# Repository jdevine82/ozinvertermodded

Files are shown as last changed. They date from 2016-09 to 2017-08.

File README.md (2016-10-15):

# ozinvertermodded
This git is an opensource project. The orginal design comes from a bloke on Finders Island going by the handle of OZTULES.
He has given the design to the public domain. I have simply penned the schematic down by reverse engineering his PCB as this was not 
written down anywhere. The files here contain the basic version and also a version coming with switchmode regulators. Free for anyone to use.
4/09/16 reworked with switchmode ps for 48-12v conversion. Changed pcb to 10x10. Use this type of regulator http://www.ebay.com.au/itm/DC-DC-Converter-4-5-60V-Adjustable-Step-Down-Buck-LM2596HV-Power-Supply-Module-/261942503087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

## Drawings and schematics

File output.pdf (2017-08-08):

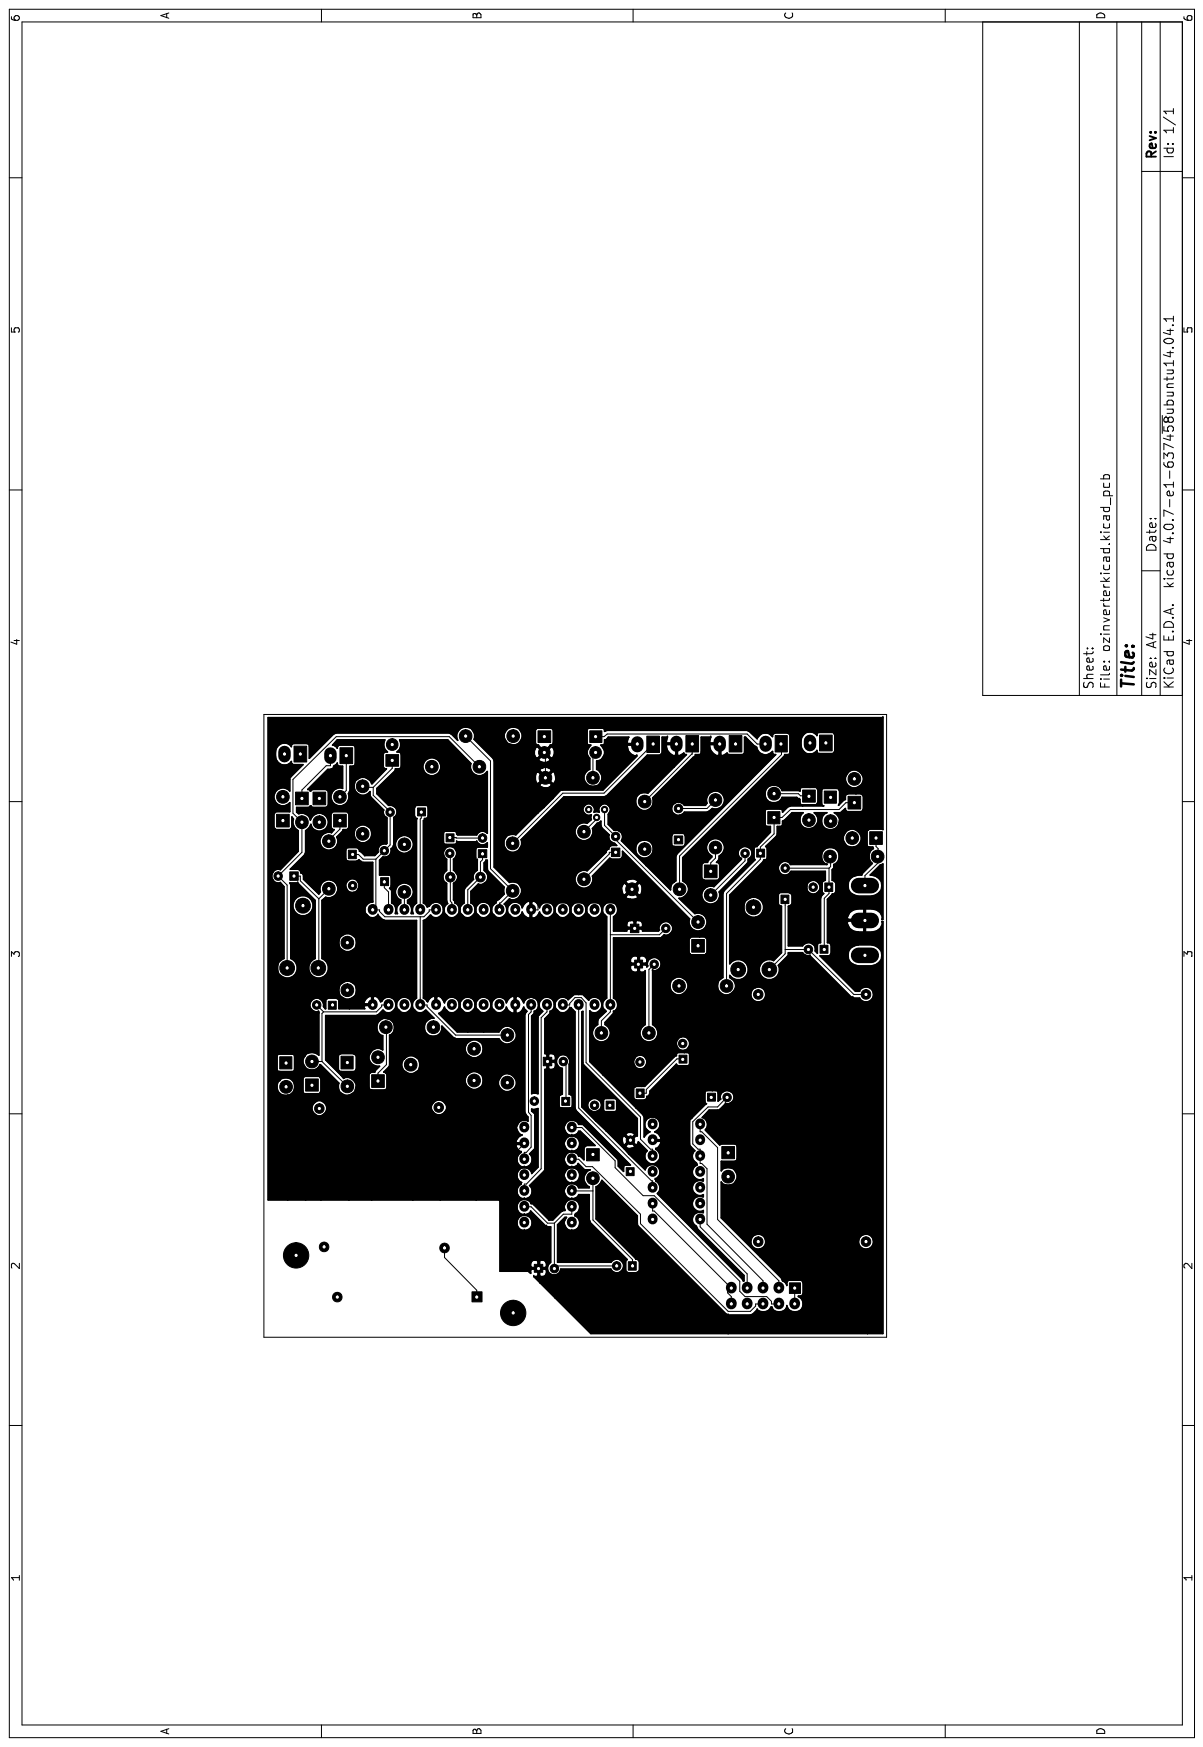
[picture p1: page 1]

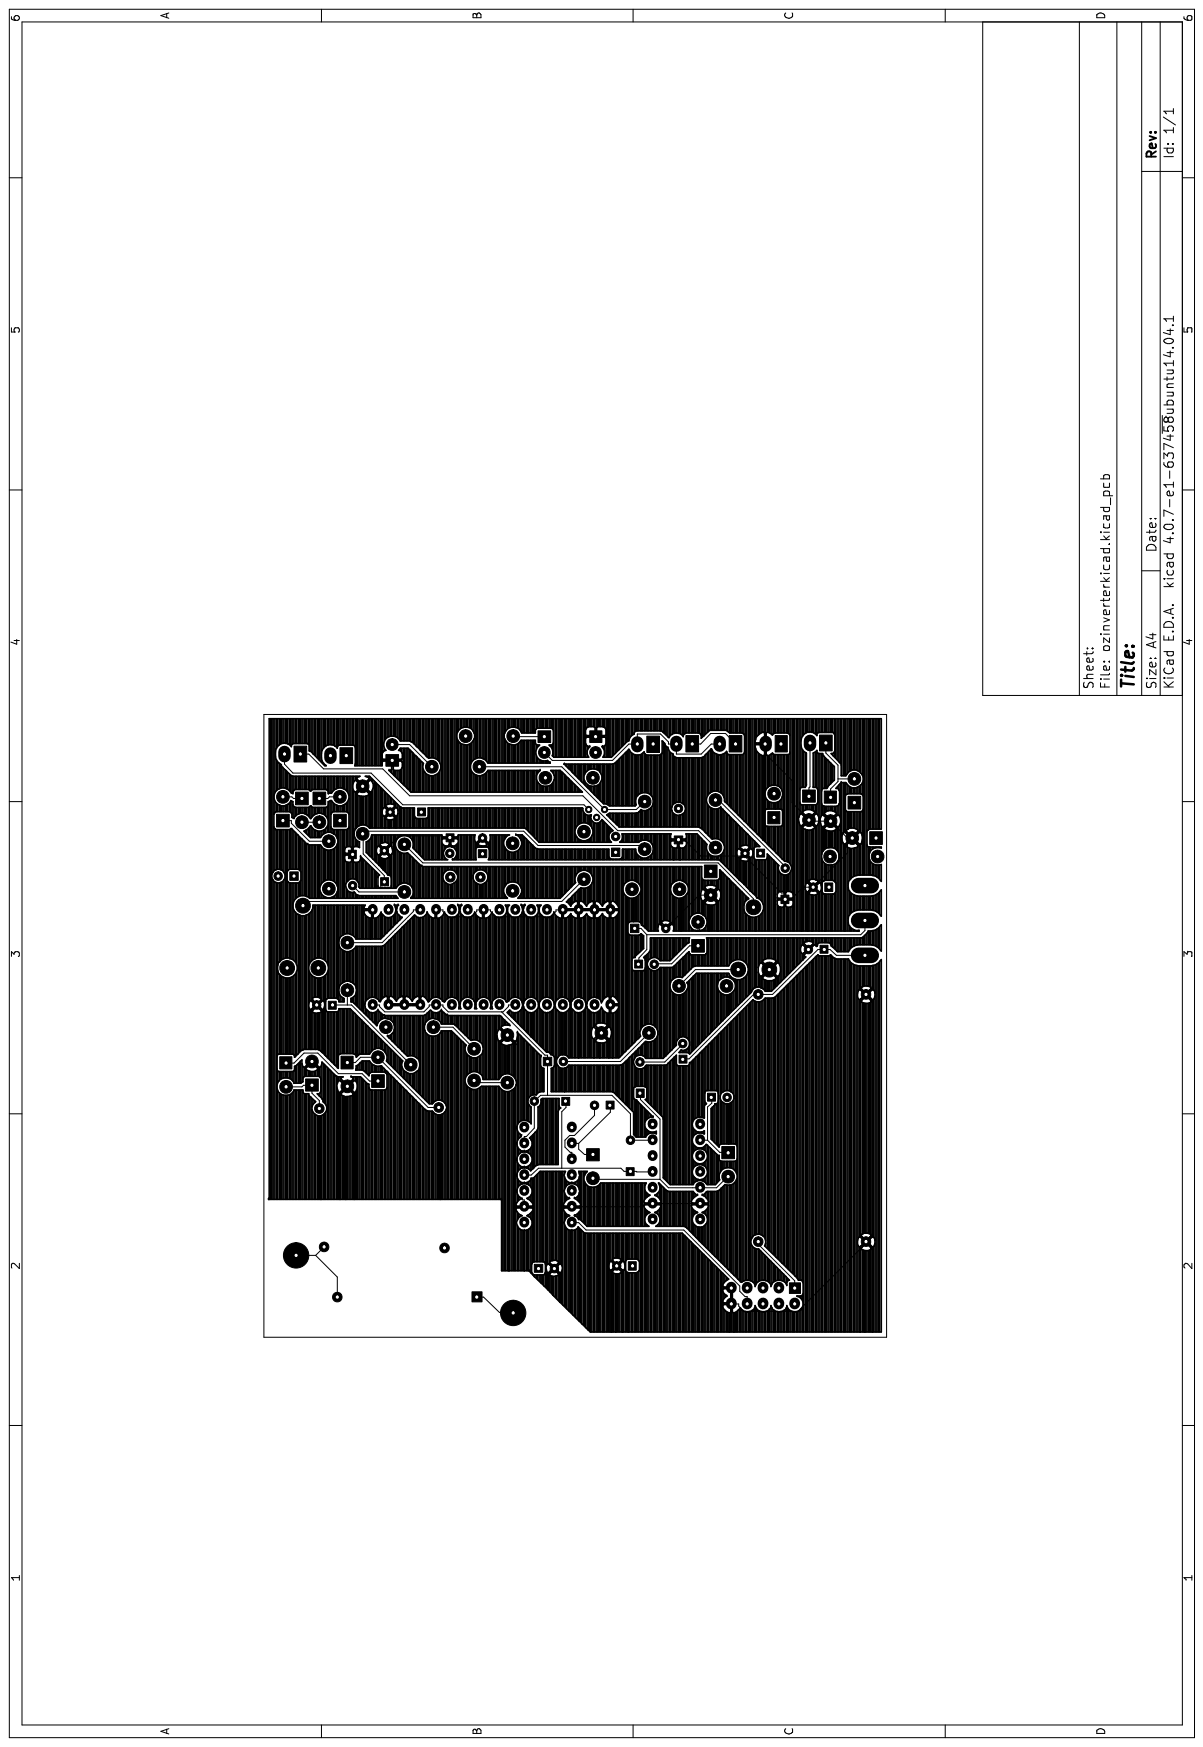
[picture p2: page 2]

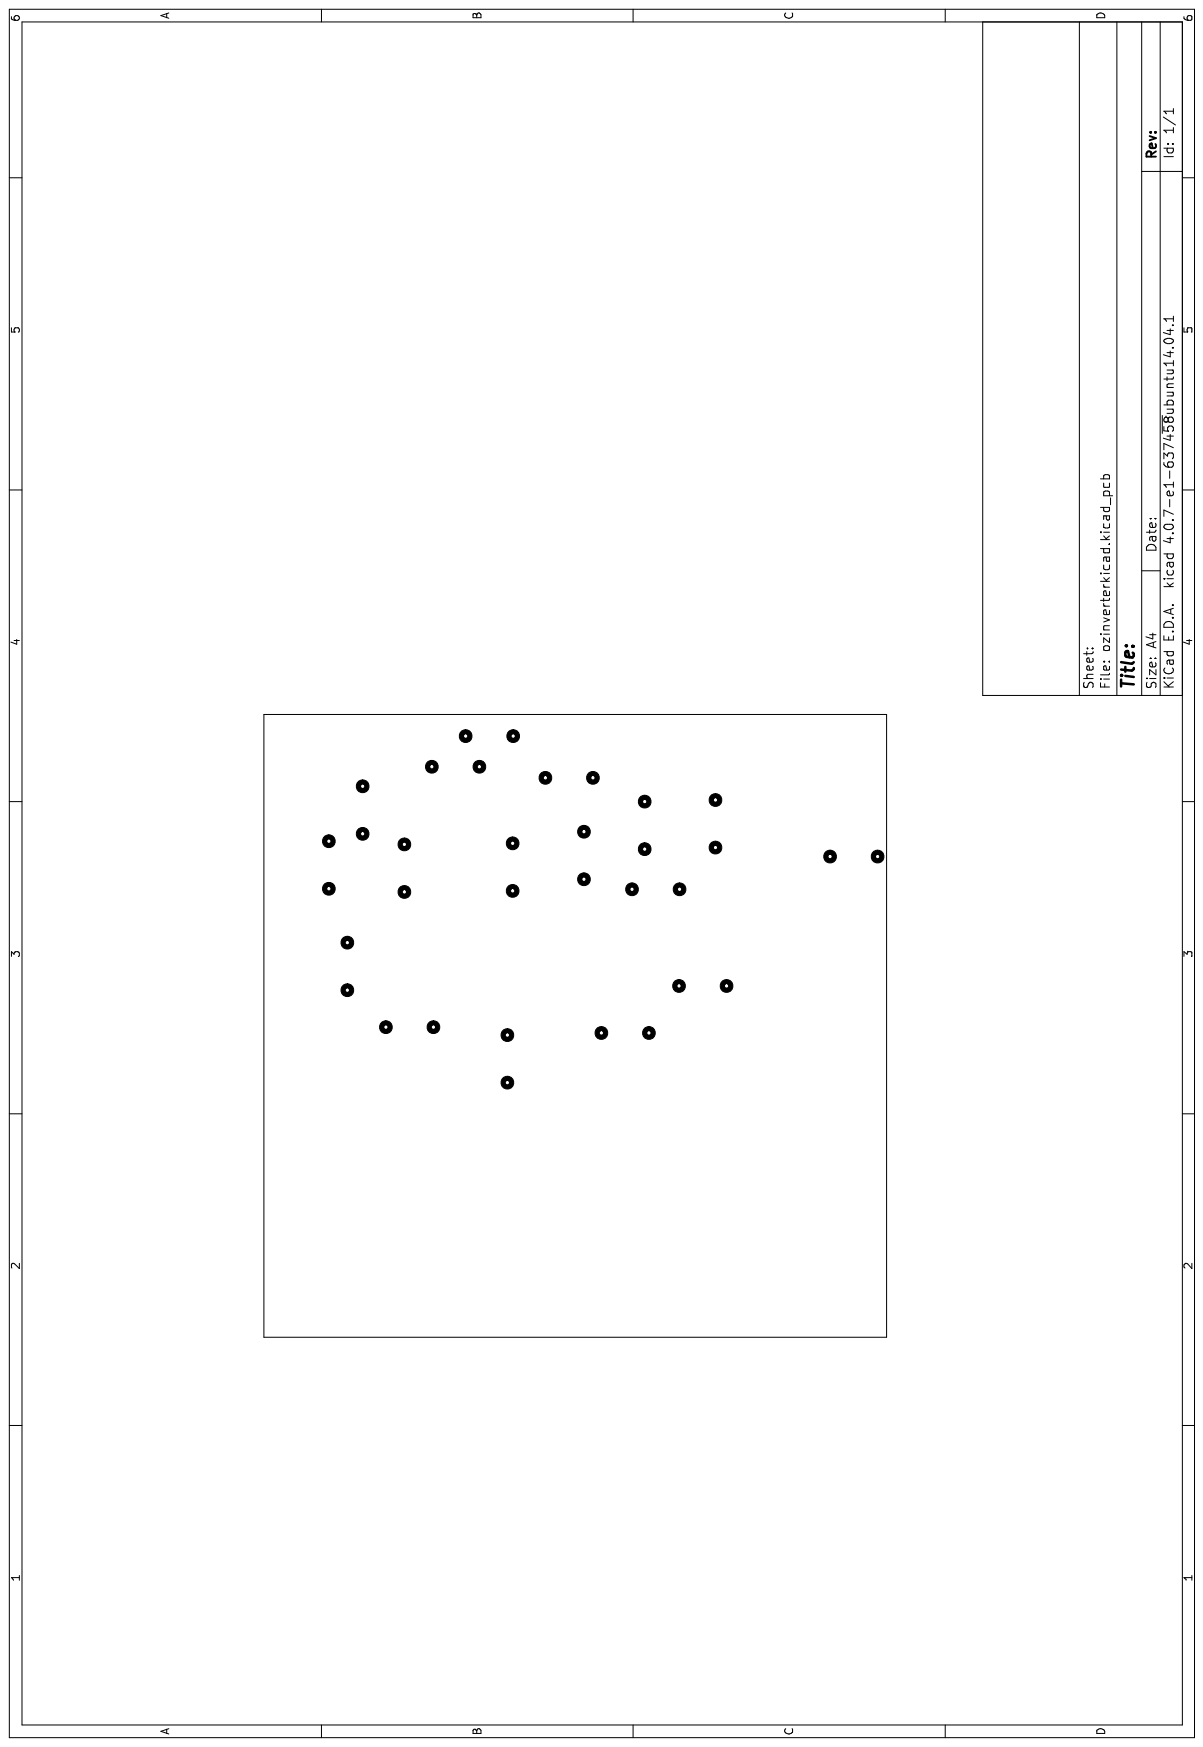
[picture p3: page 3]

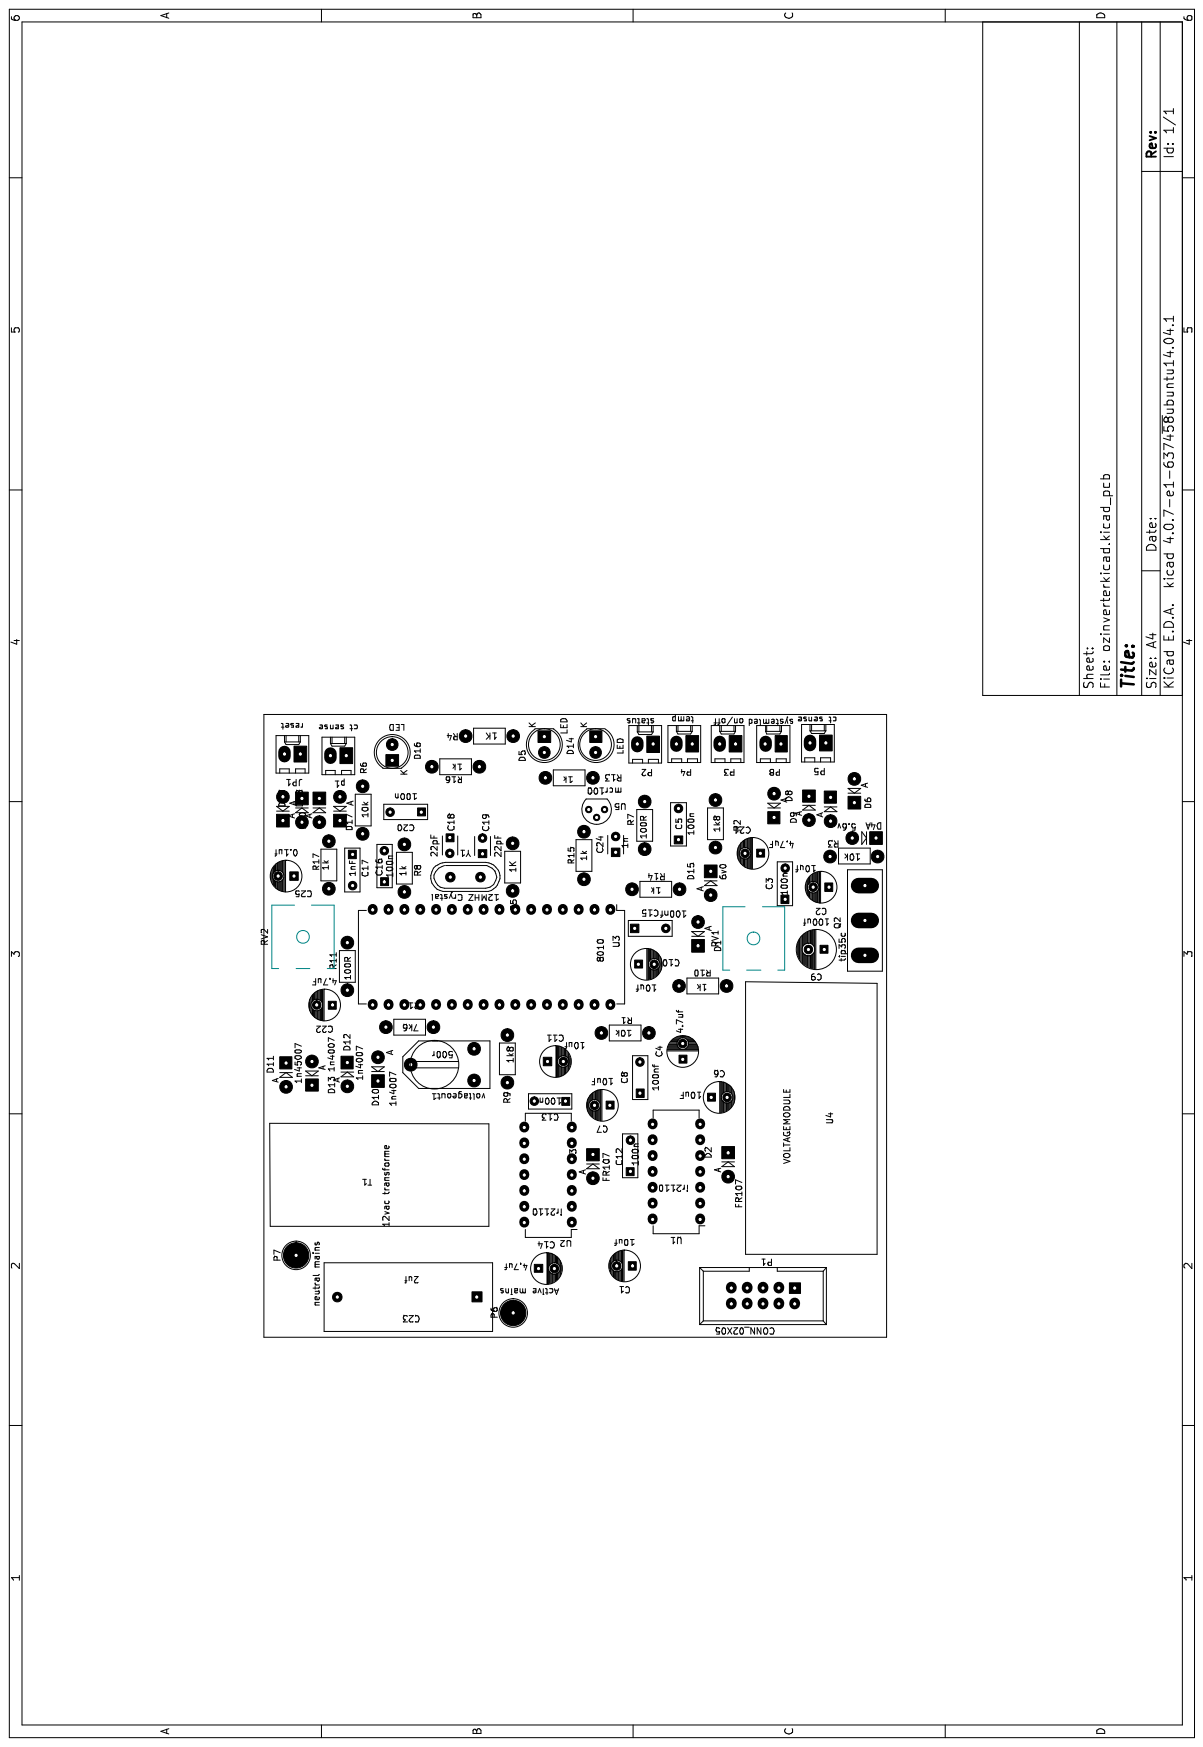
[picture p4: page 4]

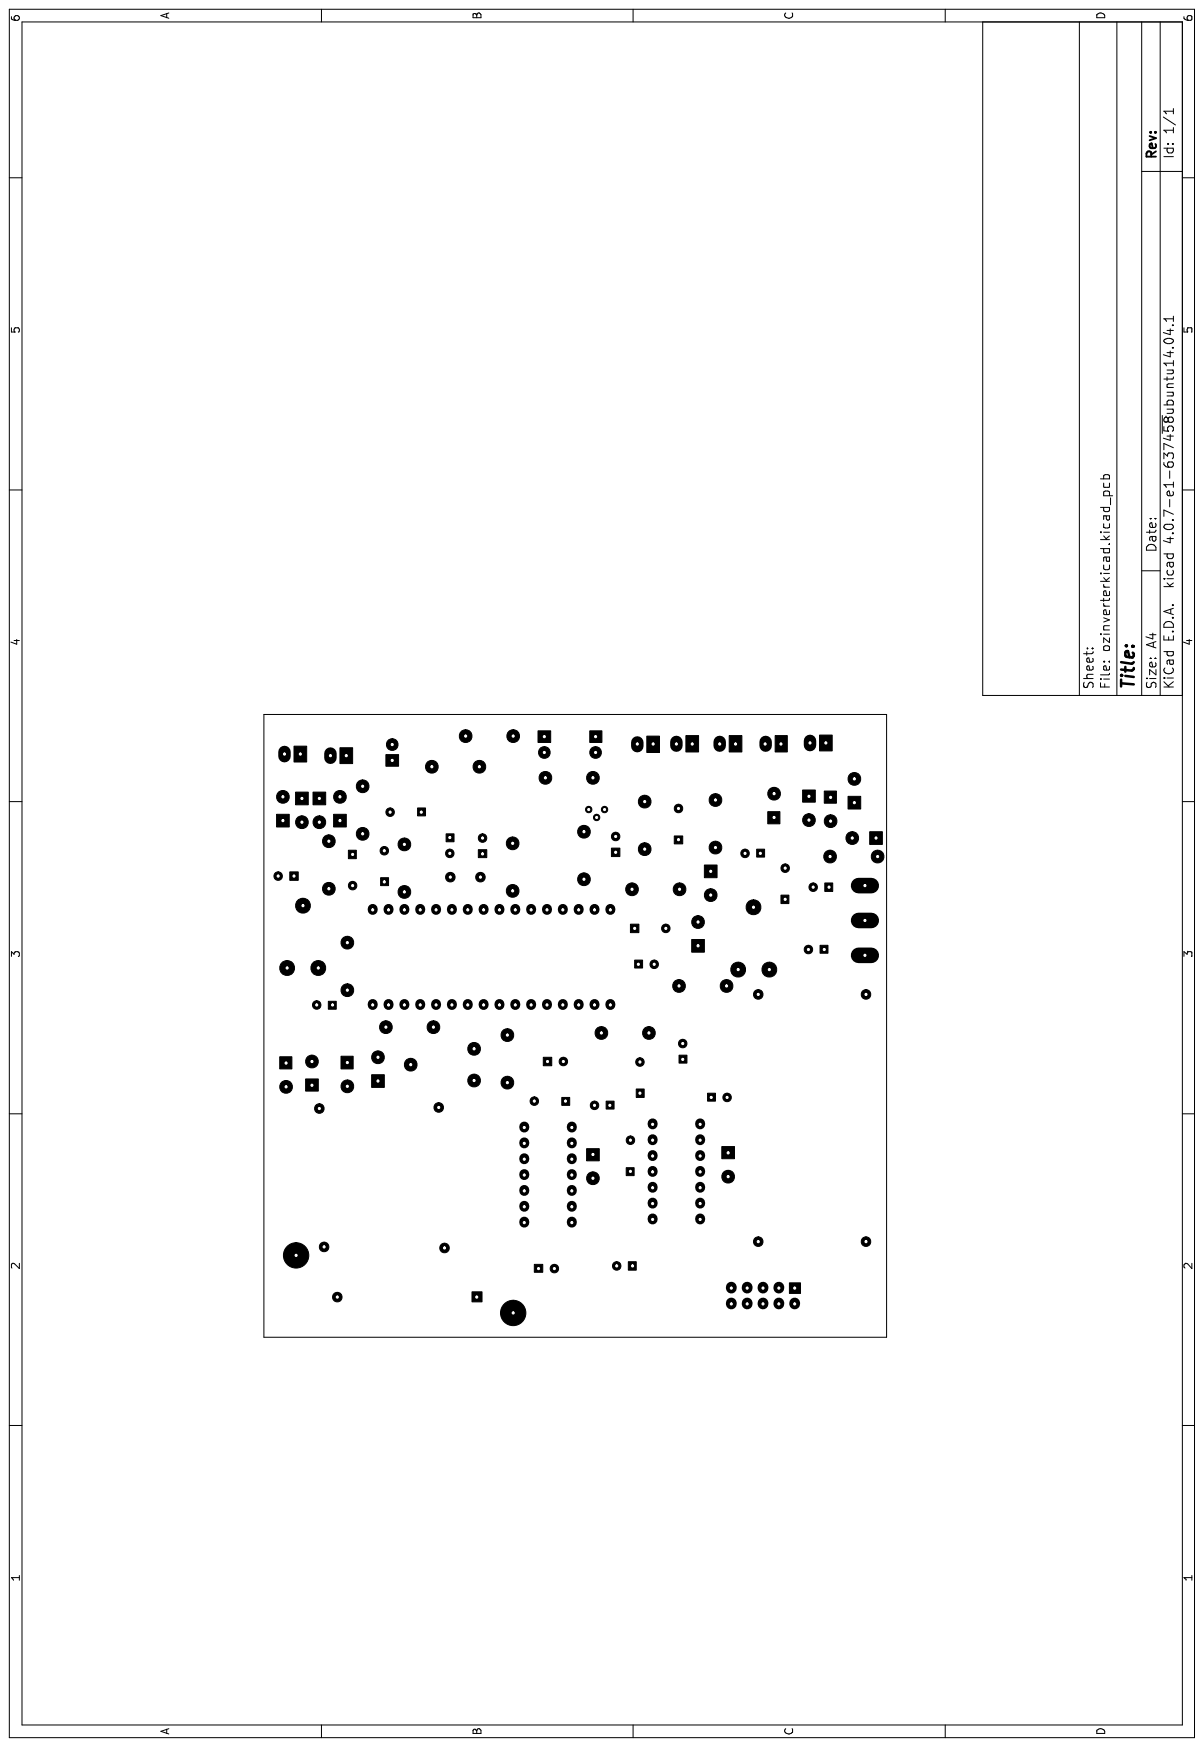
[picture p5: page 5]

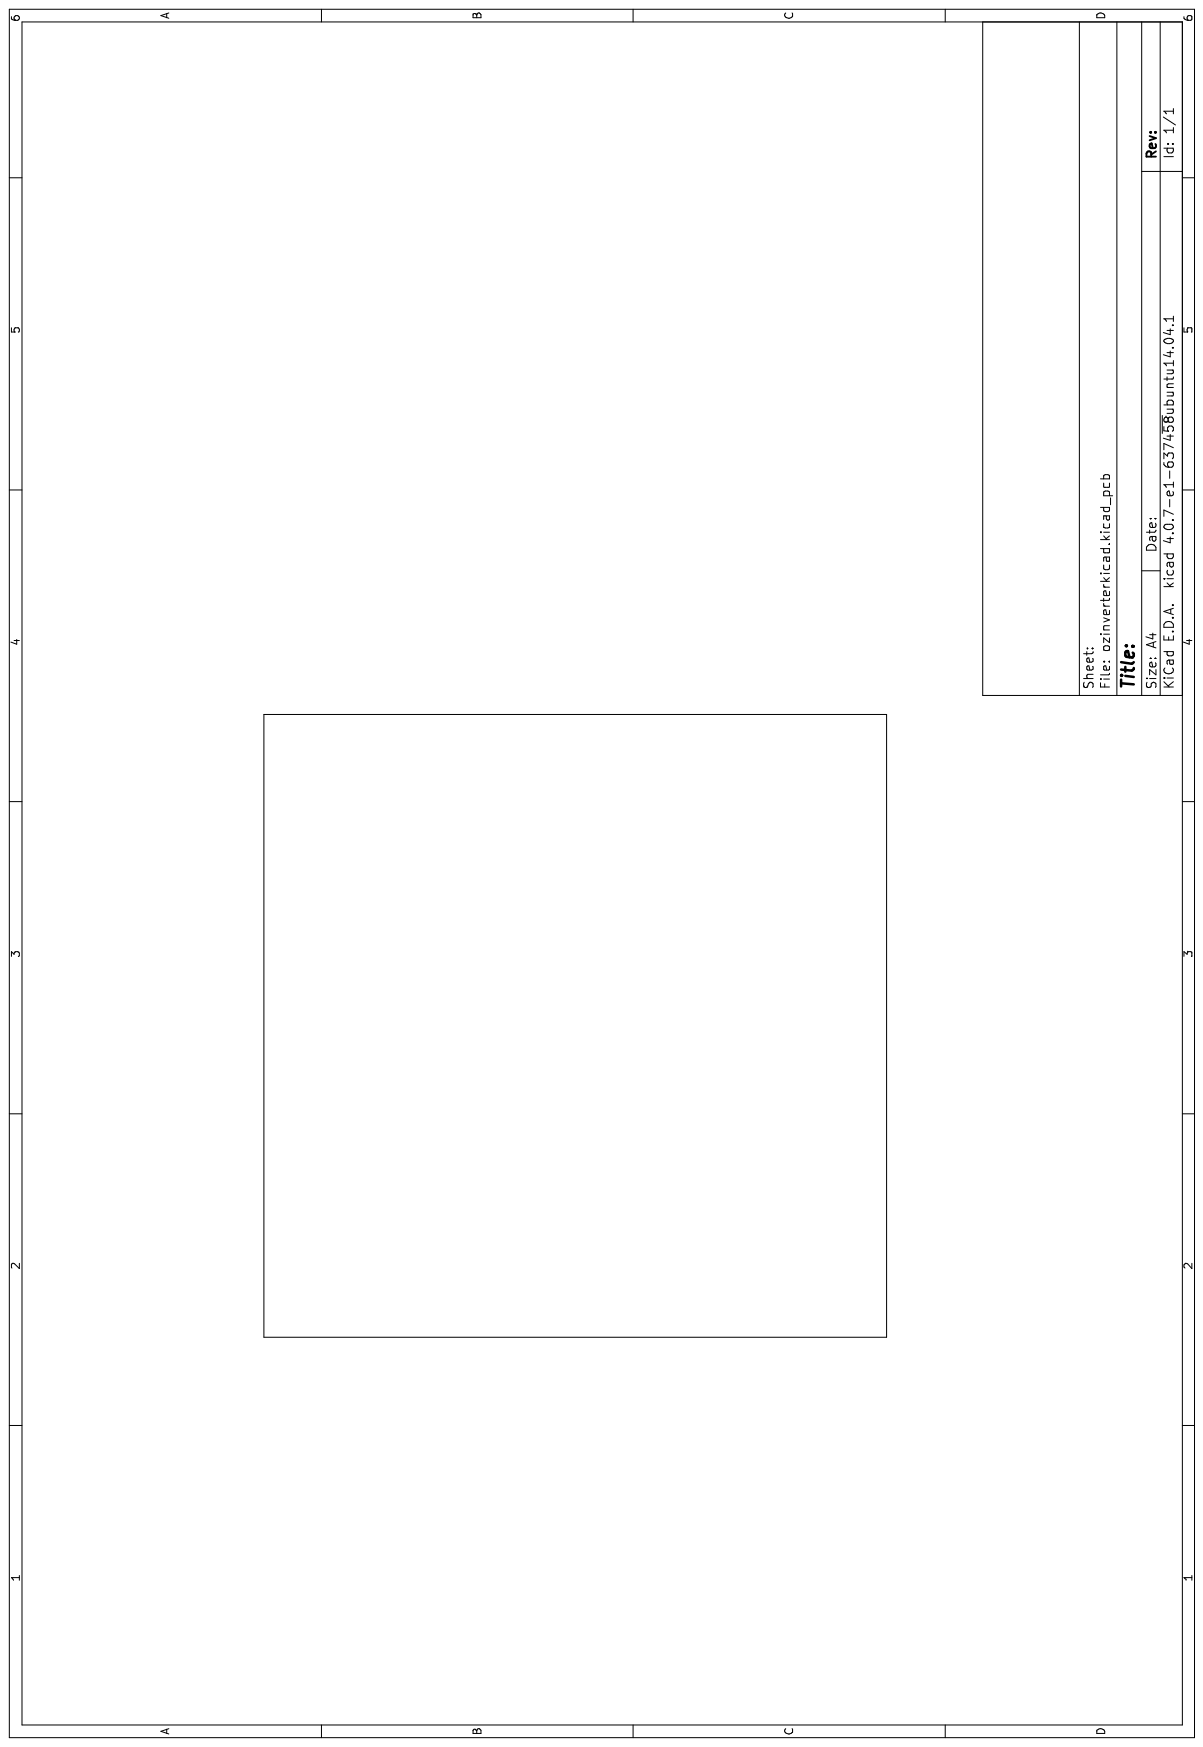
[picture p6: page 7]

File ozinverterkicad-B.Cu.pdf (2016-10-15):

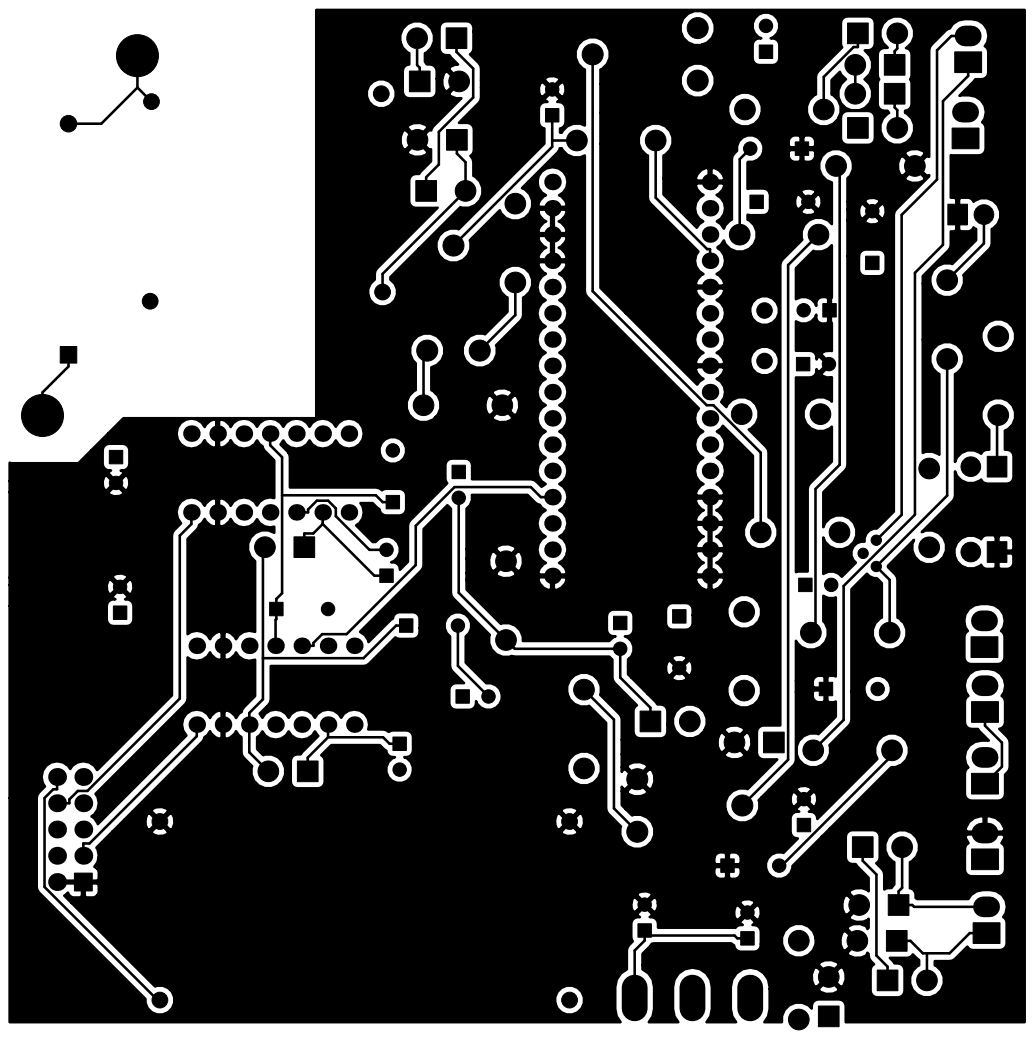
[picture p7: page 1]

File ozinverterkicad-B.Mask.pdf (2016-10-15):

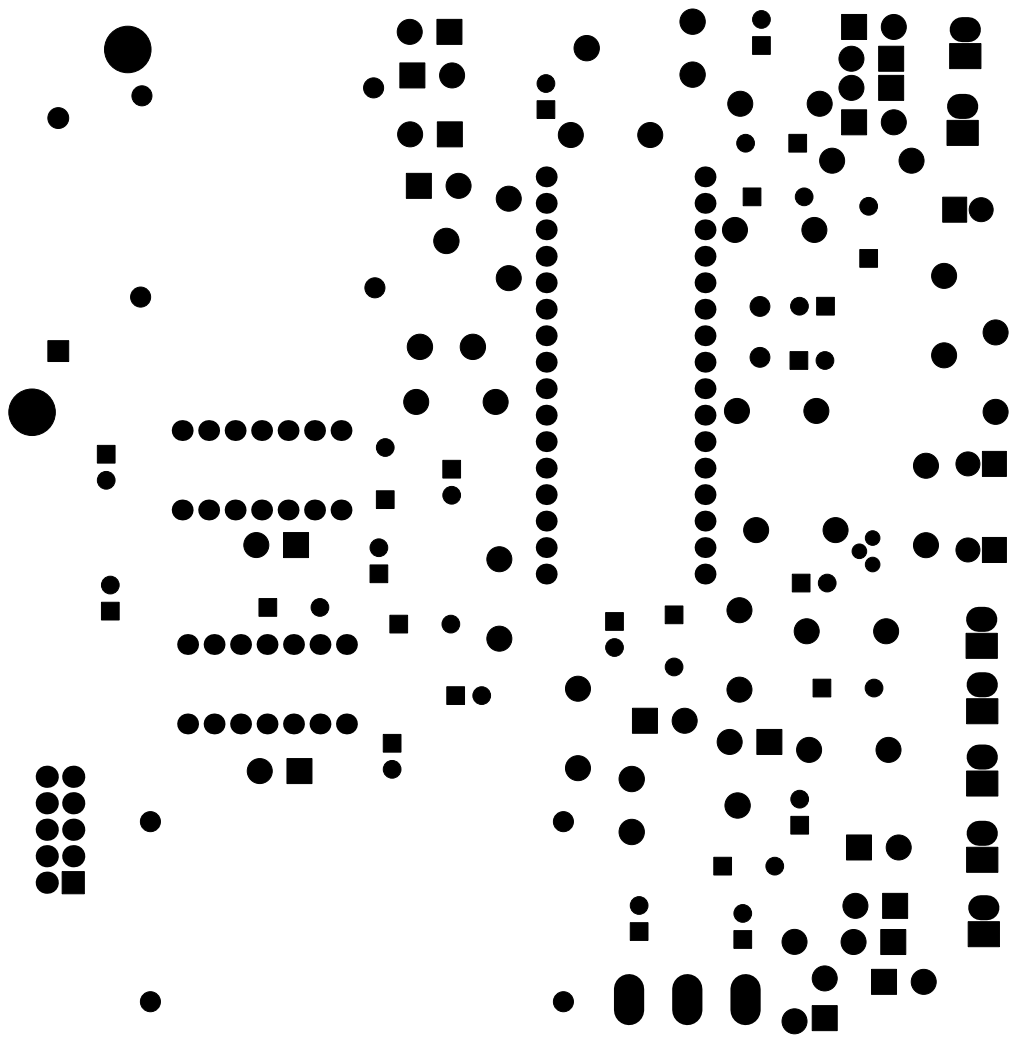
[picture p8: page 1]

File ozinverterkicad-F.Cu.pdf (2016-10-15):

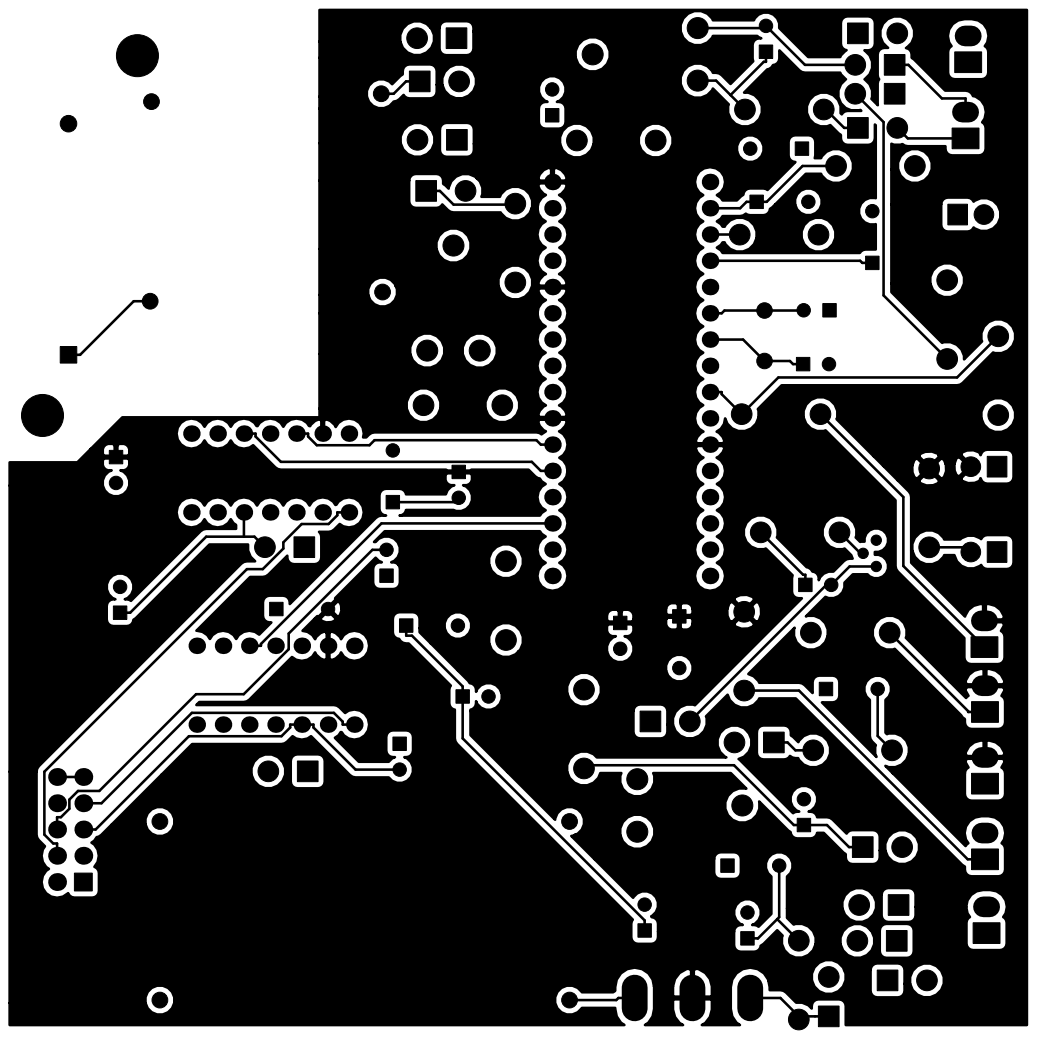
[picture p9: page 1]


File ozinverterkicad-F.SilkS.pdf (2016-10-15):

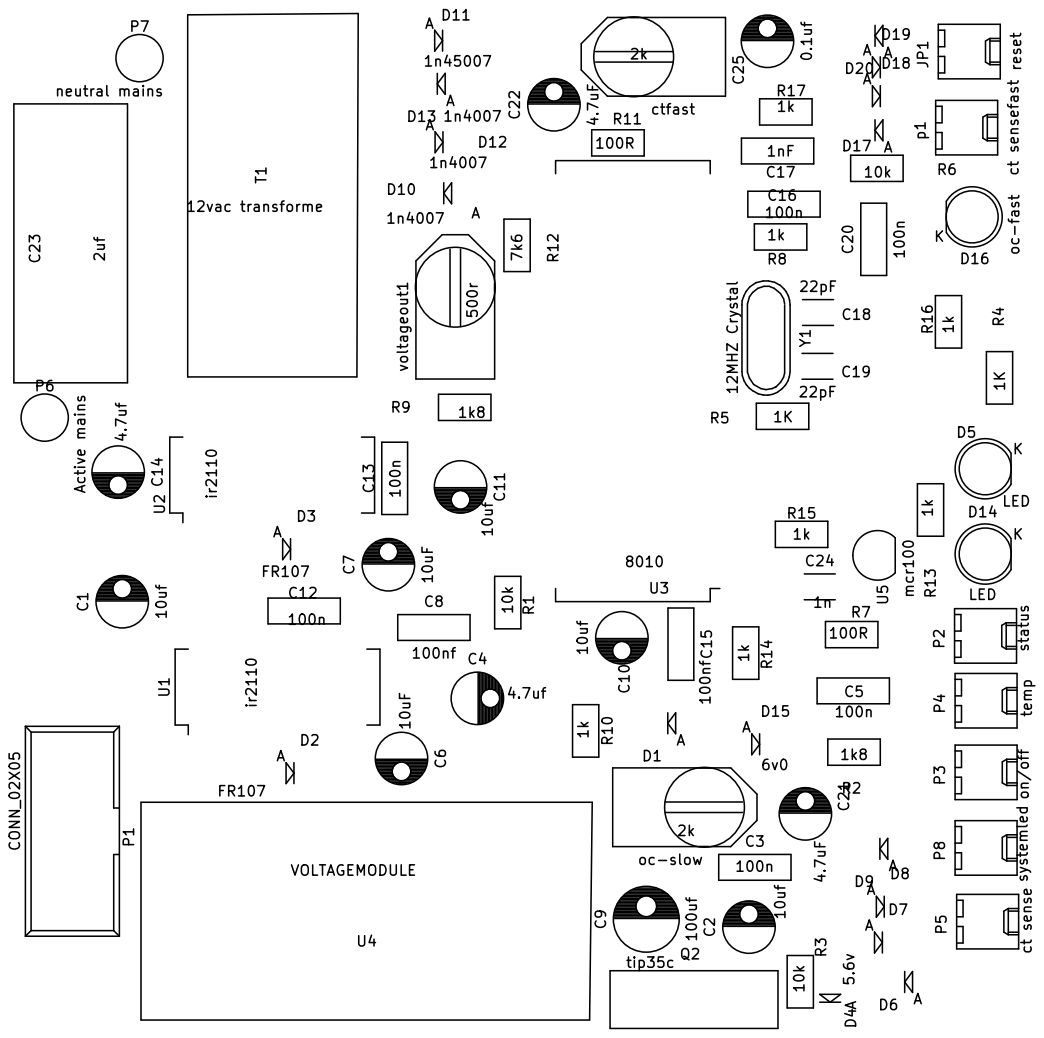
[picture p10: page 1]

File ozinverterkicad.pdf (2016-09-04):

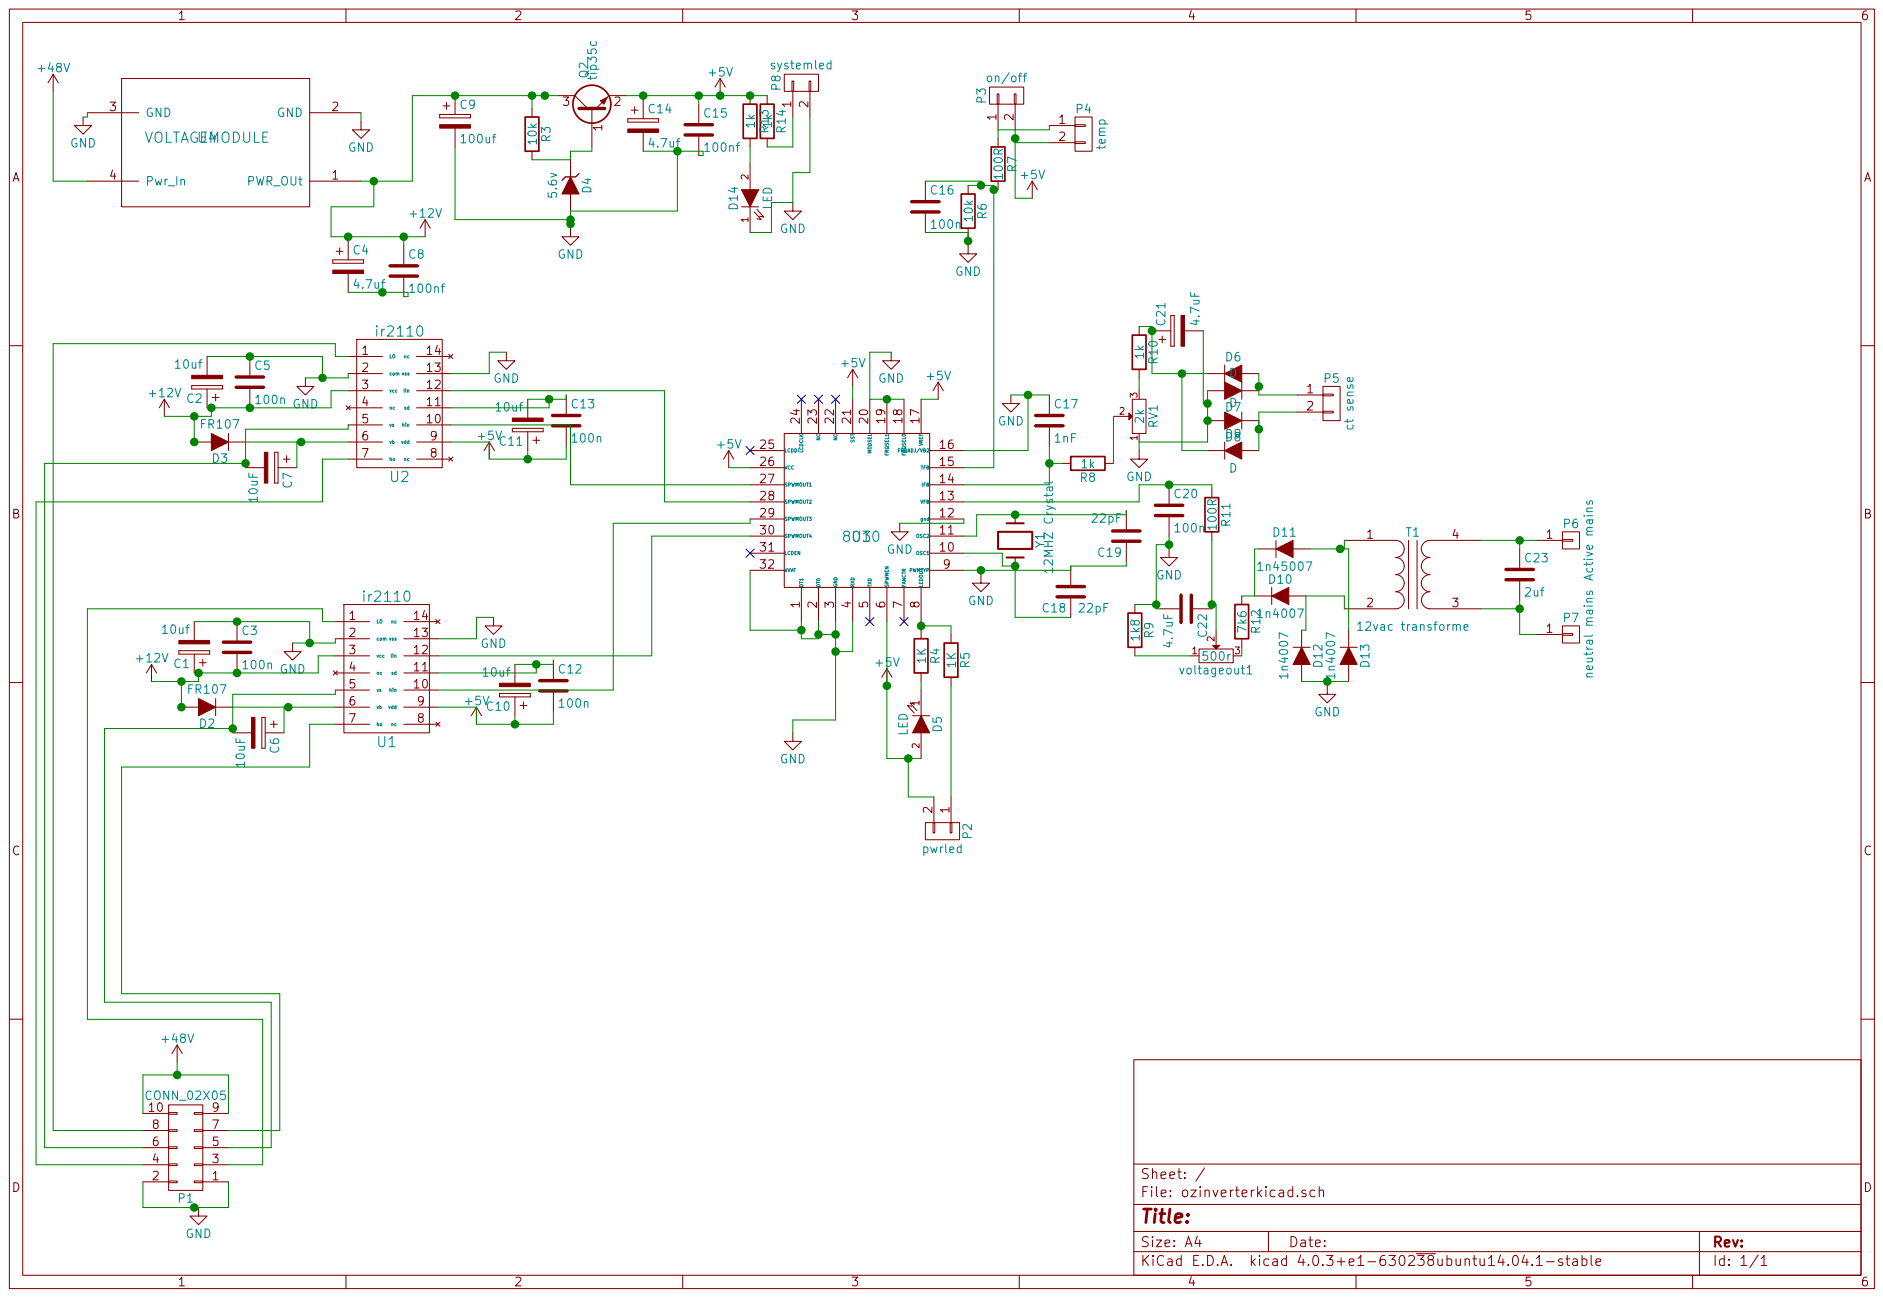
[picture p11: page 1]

2uf 1 P6 Active mains 1 P7 neutral mains C17

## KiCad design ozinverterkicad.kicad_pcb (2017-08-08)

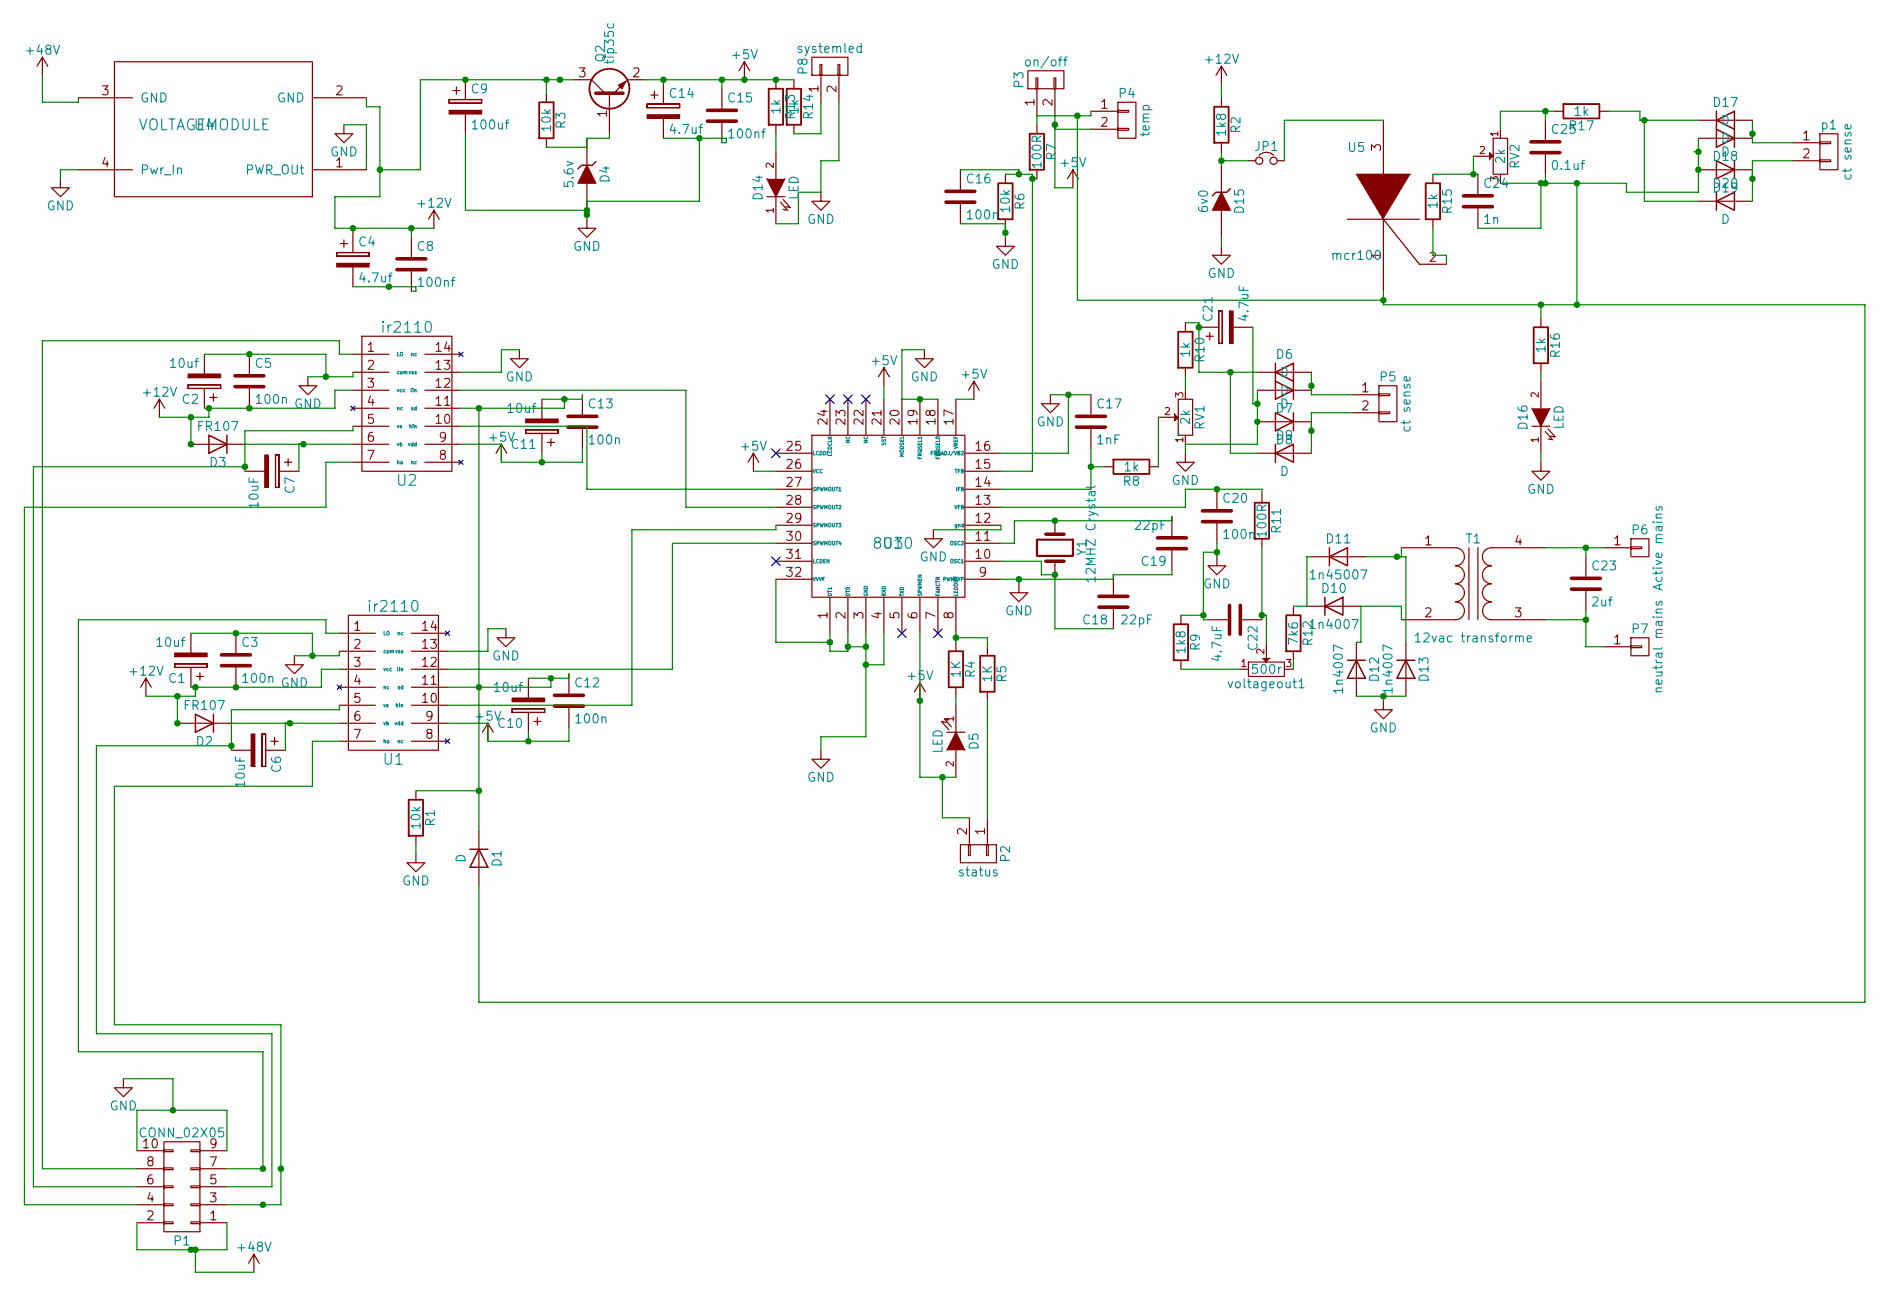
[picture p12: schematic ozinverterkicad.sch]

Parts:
C1, C2: 10uf; C_Radial_D5_L6_P2.5
C3, C5, C12, C13, C16, C20: 100n; C_Rect_L7_W2.5_P5
C4, C14: 4.7uf; C_Radial_D5_L6_P2.5
C6, C7: 10uF; C_Radial_D5_L6_P2.5
C8, C15: 100nf; C_Rect_L7_W2.5_P5
C9: 100uf; C_Radial_D6.3_L11.2_P2.5
C10, C11: 10uf; C_Radial_D5_L11_P2.5
C17: 1nF; C_Rect_L7_W2.5_P5
C18, C19: 22pF; C_Disc_D3_P2.5
C21, C22: 4.7uF; C_Radial_D5_L6_P2.5
C23: 2uf; C_Rect_L27_W11_P22
C24: 1n; C_Disc_D3_P2.5
C25: 0.1uf; C_Radial_D5_L6_P2.5
D1, D6, D7, D8, D9, D17, D18, D19, D20: D; Diode_DO-41_SOD81_Vertical_AnodeUp
D2, D3: FR107; Diode_DO-41_SOD81_Vertical_AnodeUp
D4: 5.6v; Diode_DO-41_SOD81_Vertical_AnodeUp
D5, D14, D16: LED; LED-5MM
D10, D12, D13: 1n4007; Diode_DO-41_SOD81_Vertical_AnodeUp
D11: 1n45007; Diode_DO-41_SOD81_Vertical_AnodeUp
D15: 6v0; Diode_DO-41_SOD81_Vertical_AnodeUp
JP1: reset; Molex_KK-6410-02_02x2.54mm_Straight
P1: CONN_02X05; IDC_Header_Straight_10pins
P2: status; Molex_KK-6410-02_02x2.54mm_Straight
P3: on/off; Molex_KK-6410-02_02x2.54mm_Straight
P4: temp; Molex_KK-6410-02_02x2.54mm_Straight
P5: ct sense; Molex_KK-6410-02_02x2.54mm_Straight
P6: Active mains; 1pin
P7: neutral mains; 1pin
P8: systemled; Molex_KK-6410-02_02x2.54mm_Straight
Q2: tip35c; TO-247_Vertical_Neutral123
R1, R3, R6: 10k; Resistor_Horizontal_RM7mm
R2, R9: 1k8; Resistor_Horizontal_RM7mm
R4, R5: 1K; Resistor_Horizontal_RM7mm
R7, R11: 100R; Resistor_Horizontal_RM7mm
R8, R10, R13, R14, R15, R16, R17: 1k; Resistor_Horizontal_RM7mm
R12: 7k6; Resistor_Horizontal_RM7mm
RV1, RV2: 2k; RV2X4
T1: 12vac transforme; 3wtransformer
U1, U2: ir2110; DIP-14_W7.62mm
U3: 8010; DIP-32_W15.24mm
U4: VOLTAGEMODULE; lm2596hvsmodule
U5: mcr100; TO-92_Molded_Narrow
Y1: 12MHZ Crystal; Crystal_HC49-U_Vertical
p1: ct sense; Molex_KK-6410-02_02x2.54mm_Straight
voltageout1: 500r; RV2X4

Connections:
+5V: C10.1, C11.1, C12.2, C13.2, C14.1, C15.1, D5.2 (A), P2.2, P3.2, P4.2, Q2.2 (E), R13.1, R14.1, U1.9 (vdd), U2.9 (vdd), U3.6 (SPWMEN), U3.17 (VREF), U3.21 (SST), U3.26 (VCC)
+12V: C1.1, C2.1, C3.2, C4.1, C5.2, C8.1, C9.1, D2.2 (A), D3.2 (A), Q2.3 (C), R2.1, R3.1, U1.3 (vcc), U2.3 (vcc), U4.2 (GND)
+48V: P1.1, P1.2, U4.3 (GND)
GND: C1.2, C2.2, C3.1, C5.1, C9.2, C14.2, C15.2, C16.2, C17.1, C18.2, C19.1, C20.2, C21.2, C22.2, D4.2 (A), D7.2 (A), D8.2 (A), D12.2 (A), D13.2 (A), D14.1 (K), D15.2 (A), D16.1 (K), P1.9, P1.10, P8.2, R1.2, R6.2, R9.1, RV1.1, U1.2 (com), U1.13 (vss), U2.2 (com), U2.13 (vss), U3.1 (DT1), U3.2 (DT0), U3.3 (GND), U3.4 (RXD), U3.9 (PWMTYP), U3.12 (gnd), U3.16 (FRQADJ/VB2), U3.18 (FRQSEL0), U3.19 (FRQSEL1), U3.20 (MODSEL), U3.32 (VVVF), U4.1 (PWR_OUt), U4.4 (Pwr_In)
unnamed: C4.2, C8.2
unnamed: C6.1, D2.1 (K), U1.6 (vb)
unnamed: C6.2, P1.5, U1.5 (vs)
unnamed: C7.1, D3.1 (K), U2.6 (vb)
unnamed: C7.2, P1.6, U2.5 (vs)
unnamed: C10.2, C11.2, C12.1, C13.1, D1.1 (K), R1.1, U1.11 (sd), U2.11 (sd)
unnamed: C16.1, R6.1, R7.2, U3.15 (TFB)
unnamed: C17.2, R8.2, U3.14 (IFB)
unnamed: C18.1, U3.10 (OSC1), Y1.2
unnamed: C19.2, U3.11 (OSC2), Y1.1
unnamed: C20.1, R11.1, U3.13 (VFB)
unnamed: C21.1, D6.1 (K), D9.1 (K), R10.1
unnamed: C22.1, R11.2, voltageout1.2
unnamed: C23.1, P6.1, T1.4 (SB)
unnamed: C23.2, P7.1, T1.3 (SA)
unnamed: C24.1, R15.1, RV2.2
unnamed: C24.2, C25.2, D1.2 (A), D18.2 (A), D19.2 (A), P3.1, P4.1, R7.1, R16.1, RV2.3, U5.1 (K)
unnamed: C25.1, R17.2, RV2.1
unnamed: D4.1 (K), Q2.1 (B), R3.2
unnamed: D5.1 (K), R4.2
unnamed: D6.2 (A), D7.1 (K), P5.1
unnamed: D8.1 (K), D9.2 (A), P5.2
unnamed: D10.1 (K), D11.1 (K), R12.1
unnamed: D10.2 (A), D12.1 (K), T1.2 (AB)
unnamed: D11.2 (A), D13.1 (K), T1.1 (AA)
unnamed: D14.2 (A), R13.2
unnamed: D15.1 (K), JP1.1, R2.2
unnamed: D16.2 (A), R16.2
unnamed: D17.1 (K), D20.1 (K), R17.1
unnamed: D17.2 (A), D18.1 (K), p1.1
unnamed: D19.1 (K), D20.2 (A), p1.2
unnamed: JP1.2, U5.3 (A)
unnamed: P1.3, U1.7 (ho)
unnamed: P1.4, U2.7 (ho)
unnamed: P1.7, U1.1 (LO)
unnamed: P1.8, U2.1 (LO)
unnamed: P2.1, R5.2
unnamed: P8.1, R14.2
unnamed: R4.1, R5.1, U3.8 (LEDOUT)
unnamed: R8.1, RV1.2
unnamed: R9.2, voltageout1.1
unnamed: R10.2, RV1.3
unnamed: R12.2, voltageout1.3
unnamed: R15.2, U5.2 (G)
unnamed: U1.10 (hin), U3.29 (SPWMOUT3)
unnamed: U1.12 (lin), U3.30 (SPWMOUT4)
unnamed: U2.10 (hin), U3.27 (SPWMOUT1)
unnamed: U2.12 (lin), U3.28 (SPWMOUT2)

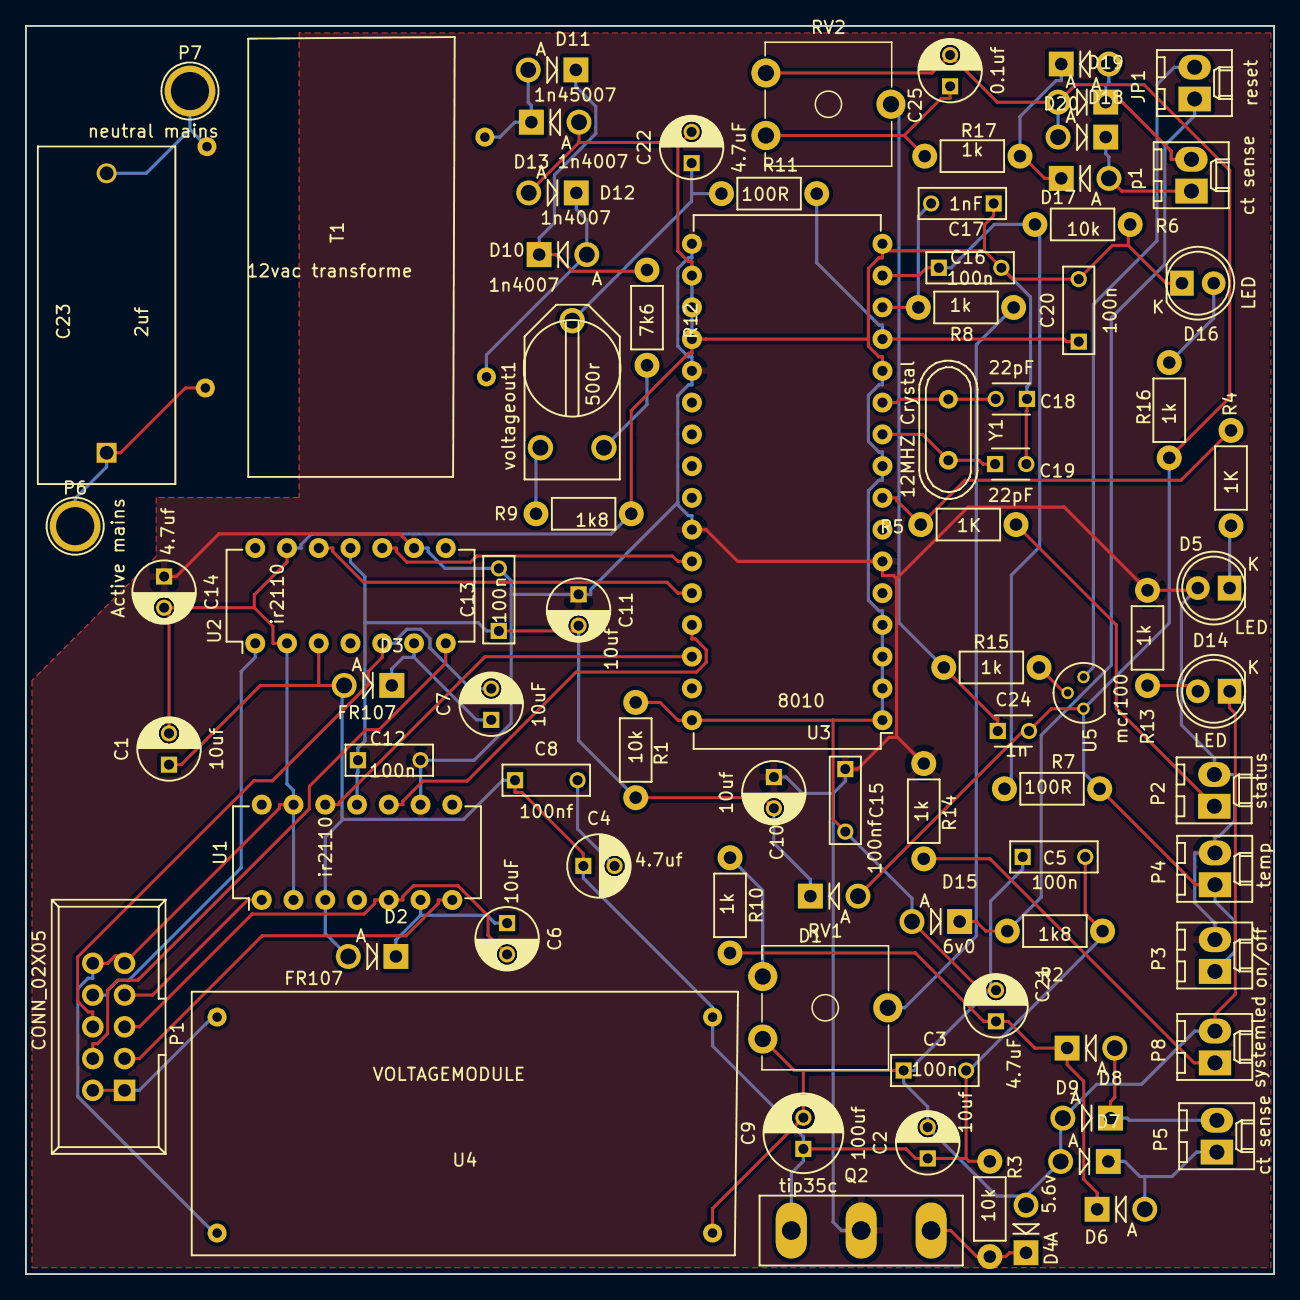
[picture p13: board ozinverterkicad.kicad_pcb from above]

Board: 2 copper layers, 99.8 x 99.8 mm, 83 parts (0 on the bottom side), 52 nets.

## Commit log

2016-09-04 added schematic in pdf
2016-10-15 added extra ct sense
    [_saved_ozinverterkicad.sch, ozinverterkicad.sch]
2016-10-15 added extra ct routed
    [ozinverterkicad-B.Cu.gbl, ozinverterkicad-B.Mask.gbs, ozinverterkicad-B.SilkS.gbo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]
2016-10-15 added pdf
    [ozinverterkicad.kicad_pcb]
2016-10-15 changedboard outline to under 100x100
    [ozinverterkicad-B.Cu.gbr, ozinverterkicad-B.Mask.gbr, ozinverterkicad-B.SilkS.gbr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]
2017-08-08 changed plug around for correct pinout
    [_saved_ozinverterkicad.sch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]
